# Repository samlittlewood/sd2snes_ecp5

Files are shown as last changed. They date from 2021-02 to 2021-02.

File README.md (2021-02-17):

Lattice ECP5 Transplant for SD2SNES
===================================

Based on https://github.com/mrehkopf/sd2snes

* Main changes are FPGA, RAM and power. The SNES interface and MCU are broadly the same as SD2SNES
* Prototype is populated with ECP5U-45F for easy development - 12F or 25F parts are available for same footprint. 
* MSU-1 DAC mods from https://github.com/DevLaTron/sd2snes
* USB-C (2.0) connector

Schematic: https://github.com/samlittlewood/sd2snes_ecp5/raw/main/RevB/sd2snes_ecp5.pdf

WARNING: This is still a prototype - it has managed to run games, but more than likely has some 'hilarious in hindsight' mistakes that have yet to be found.
 
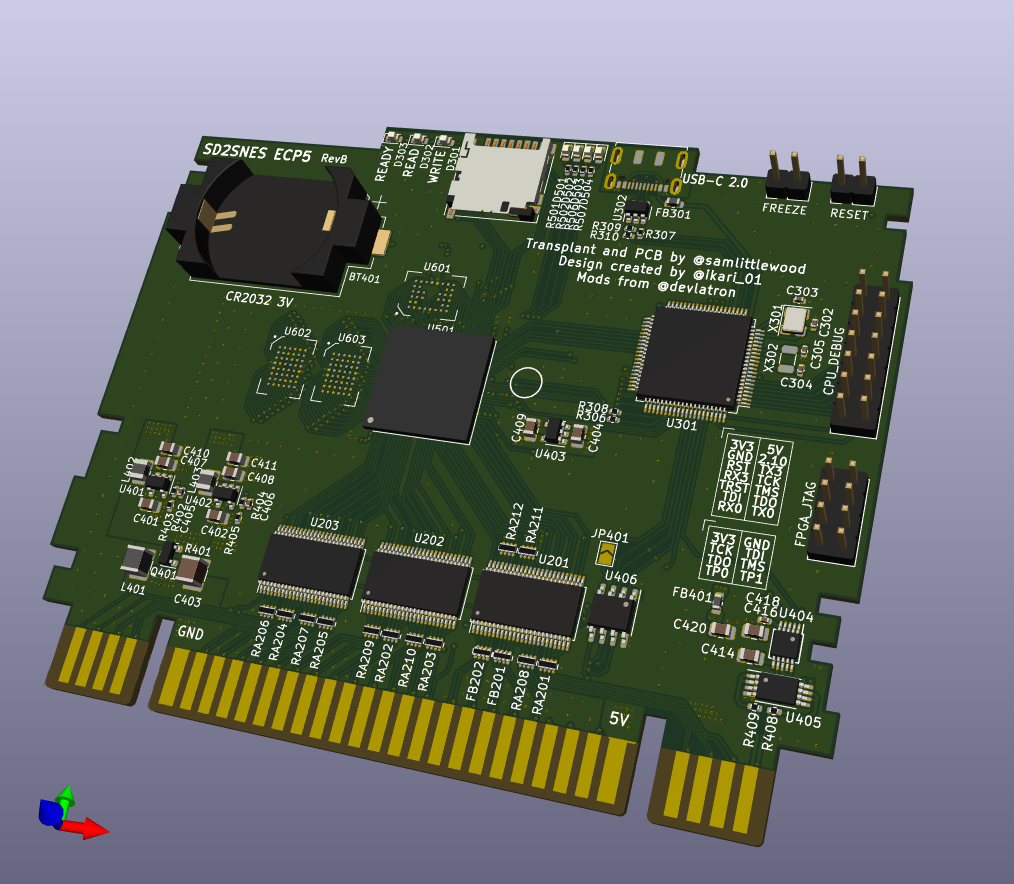
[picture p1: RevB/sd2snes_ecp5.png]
Shiny


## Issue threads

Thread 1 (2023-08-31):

Firmware Version

bigfootcontrols, 2023-08-31:
Does this fork of SD2SNES use the same firmware as mainline SD2SNES releases?  Or is there a custom firmware needed?

samlittlewood, 2023-09-04:
Hiya,

It needs custom firmware. A couple of years ago - I had a very hacked up
port of the original software & gateware, enough to get 'normal' types of
cart mostly working. I was starting to tidy it up and figure out the more
interesting carts, when the Lattice FPGA parts became unobtanium, and I
shelved it.

Looks like the parts are available again, and there has been some renewed
interest, so I'll see if I can update to latest firmware/gateware and get
it into a releasable state. The big issues are around porting the verilog
code so as to make use of the custom RAM and multipliers.

S

On Thu, 31 Aug 2023 at 18:35, bigfootcontrols ***@***.***>
wrote:

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

--
Sam Littlewood

bigfootcontrols, 2023-09-05:
That's great to hear!  It would be really cool to have a working, open-source SNES flashcart available again.  If you need beta testers I'd be interested in ordering a PCB and giving it a go, I'd be happy to put in some time testing out firmware builds.  I wish I could volunteer to help with the firmware itself but unfortunately I haven't done any coding in about 15 years lol

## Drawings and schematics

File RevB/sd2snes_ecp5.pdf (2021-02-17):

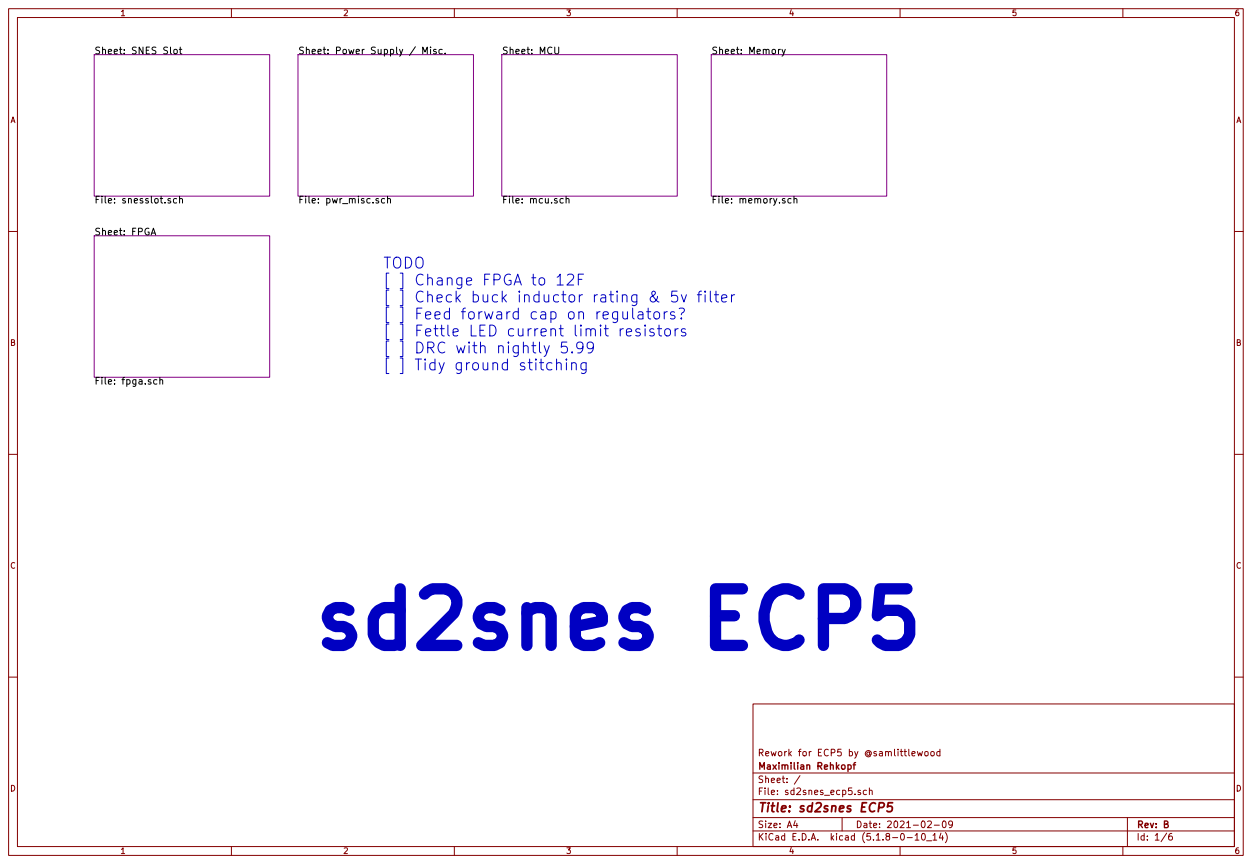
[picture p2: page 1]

File: mcu.sch Sheet: Power Supply / Misc.

TODO
[ ] Change FPGA to 12F
[ ] Check buck inductor rating & 5v filter
[ ] Feed forward cap on regulators?
[ ] Fettle LED current limit resistors
[ ] DRC with nightly 5.99
[ ] Tidy ground stitching

Rework for ECP5 by @samlittlewood
File: sd2snes_ecp5.sch Sheet: / Maximilian Rehkopf

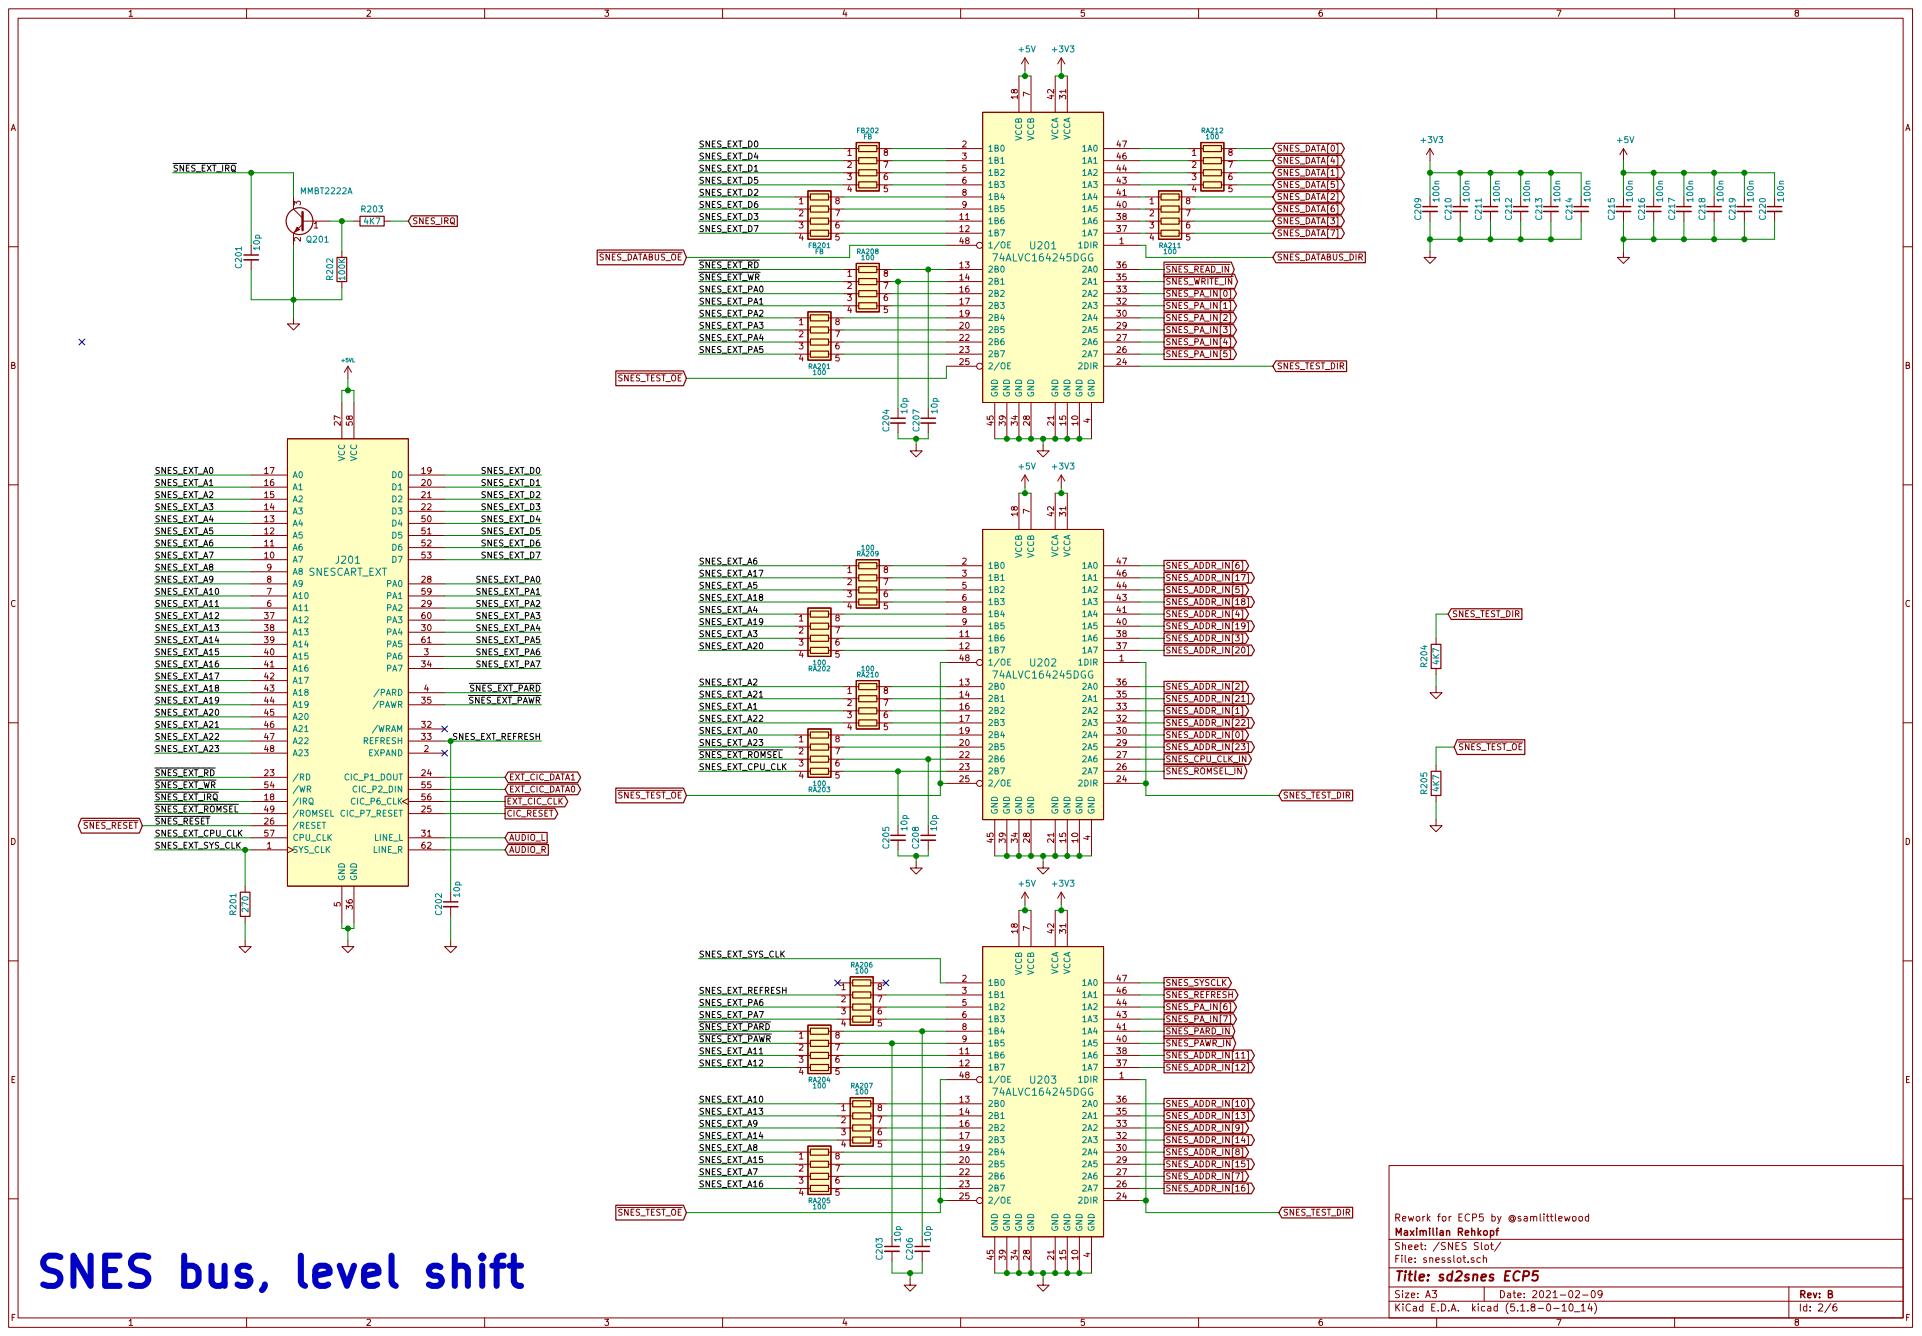
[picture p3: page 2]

SNES_EXT_A0 SNES_EXT_A1 SNES_EXT_A2 SNES_EXT_A3 SNES_EXT_A4 SNES_EXT_A5 SNES_EXT_A6 SNES_EXT_A7 SNES_EXT_A8 SNES bus, level shift

2B6 22
2B7 23

1B7 12
1/OE 48 2B0 13

File: snesslot.sch Sheet: /SNES Slot/ Maximilian Rehkopf

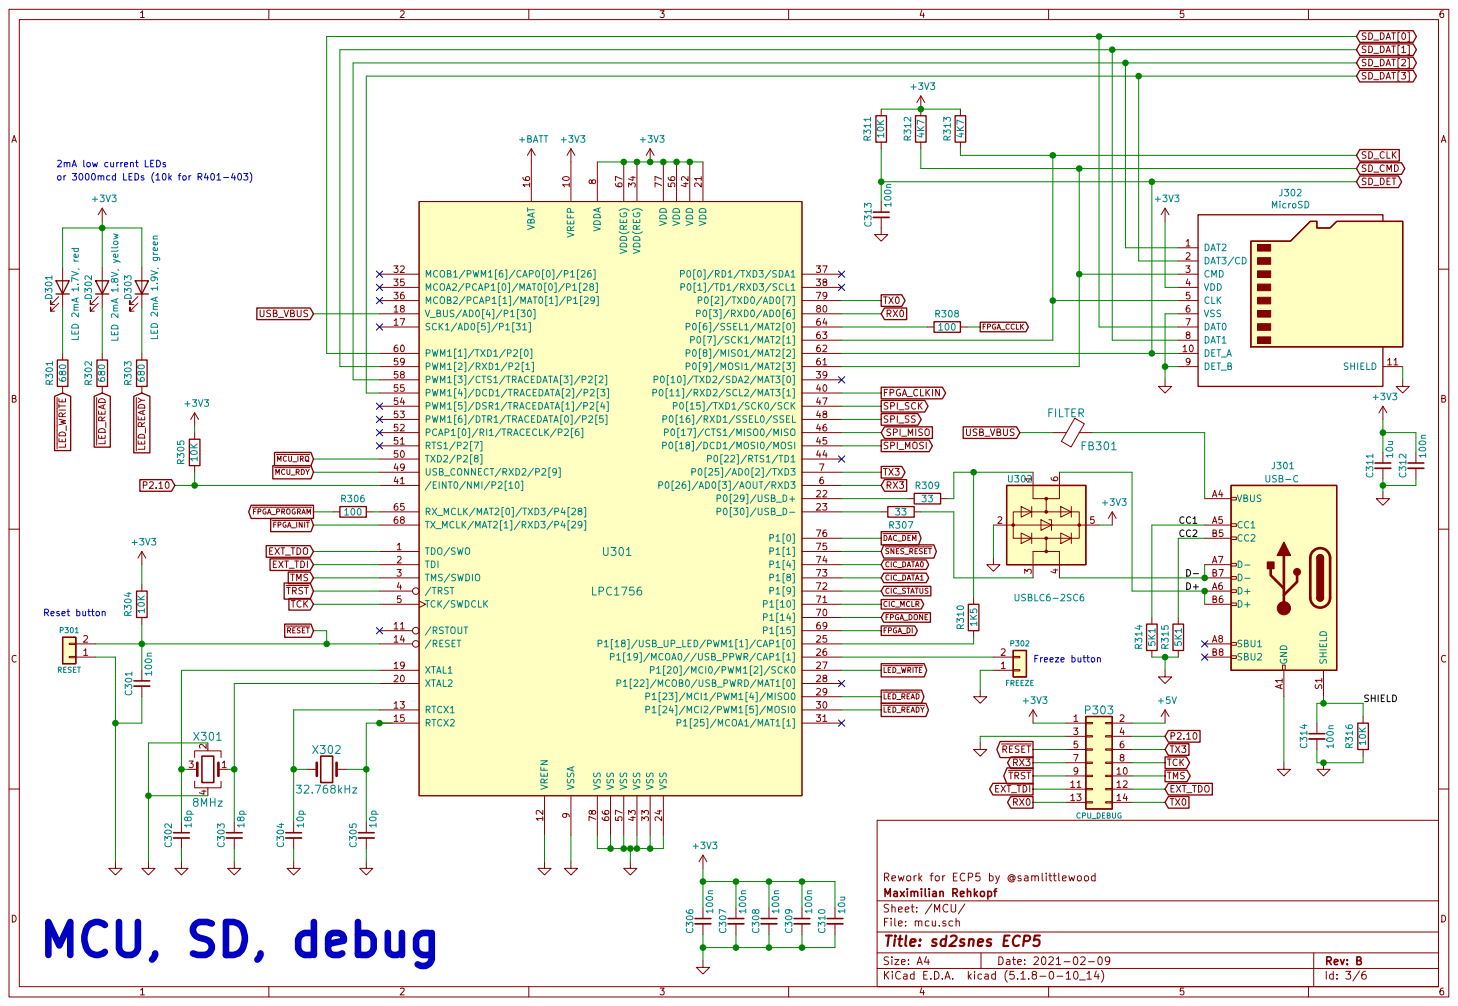
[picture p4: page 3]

or 3000mcd LEDs (10k for R401-403) 2mA low current LEDs

Freeze button Reset button

File: mcu.sch Sheet: /MCU/ Maximilian Rehkopf

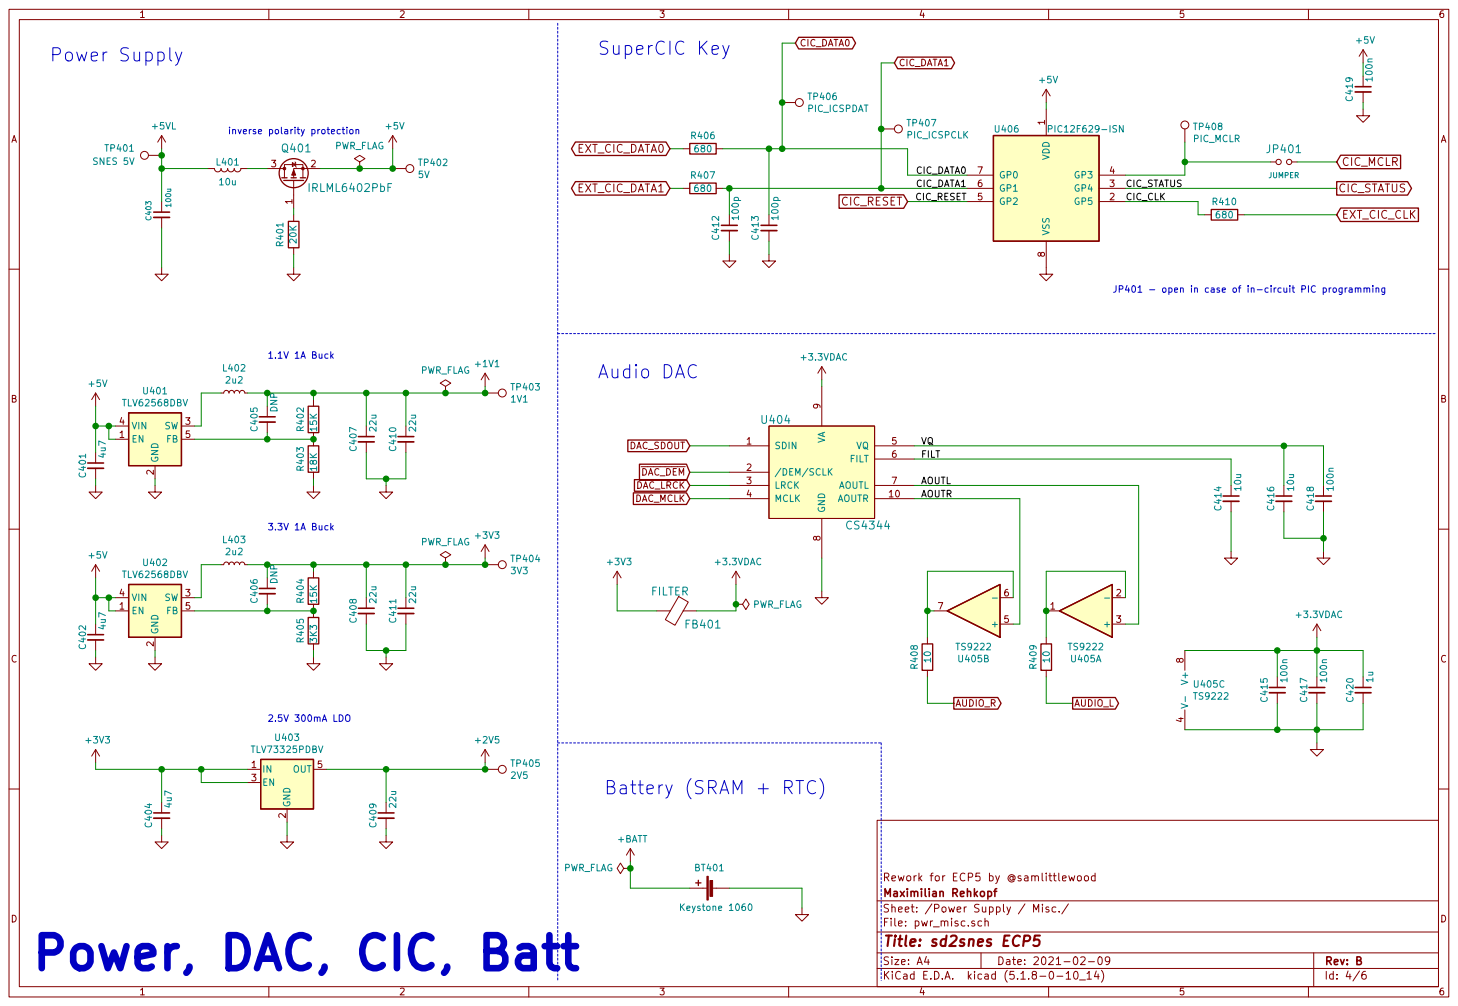
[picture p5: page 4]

SuperCIC Key Power Supply

JP401 - open in case of in-circuit PIC programming

Rework for ECP5 by @samlittlewood
Maximilian Rehkopf
Sheet: /Power Supply / Misc./
File: pwr_misc.sch
Id: 4/6 Title: sd2snes ECP5

Power, DAC, CIC, Batt

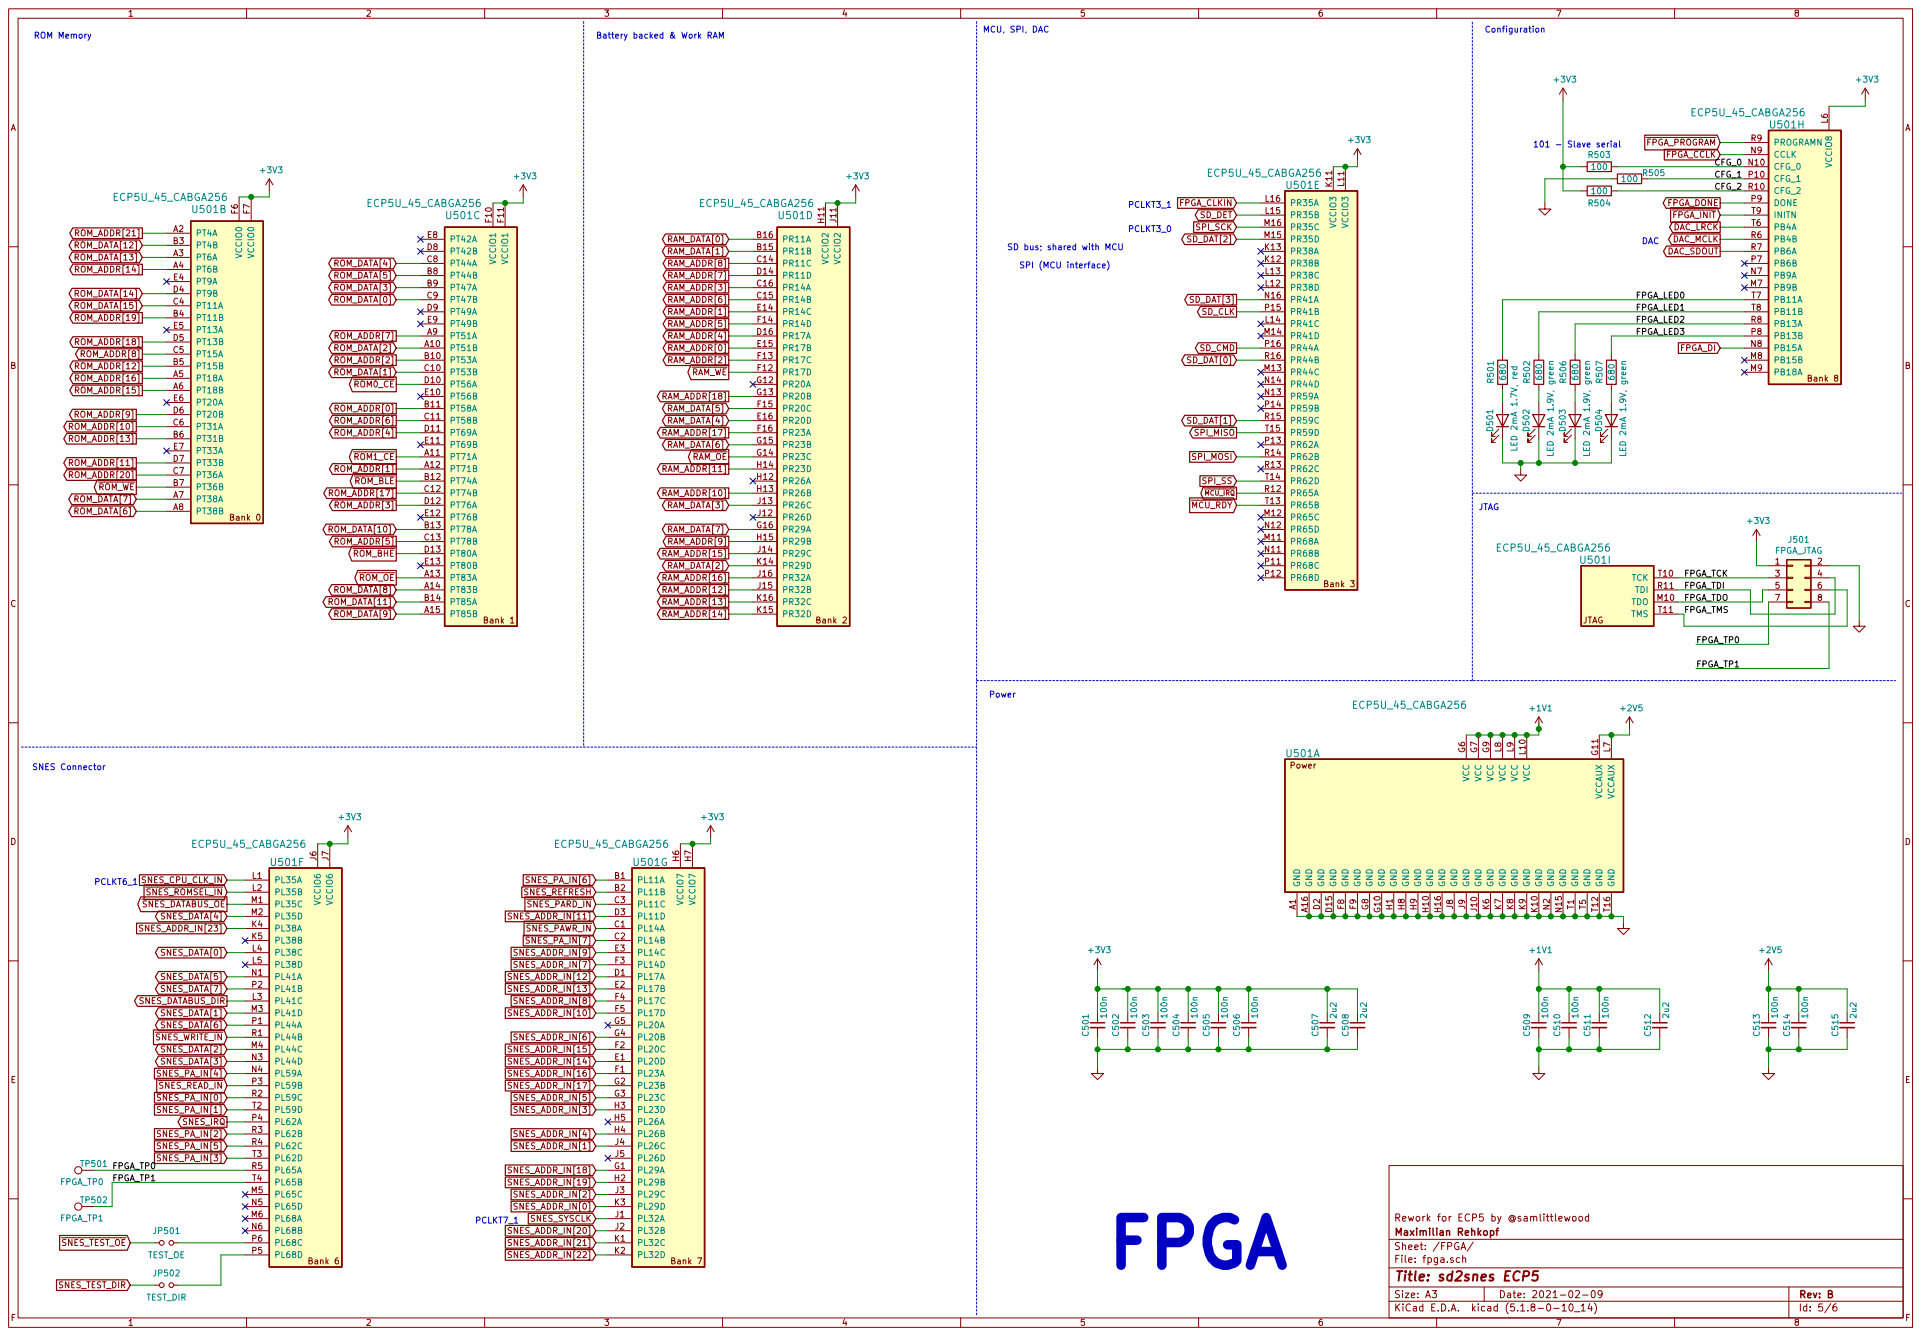
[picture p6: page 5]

SPI (MCU interface) SD bus; shared with MCU

Rework for ECP5 by @samlittlewood
File: fpga.sch Sheet: /FPGA/ Maximilian Rehkopf

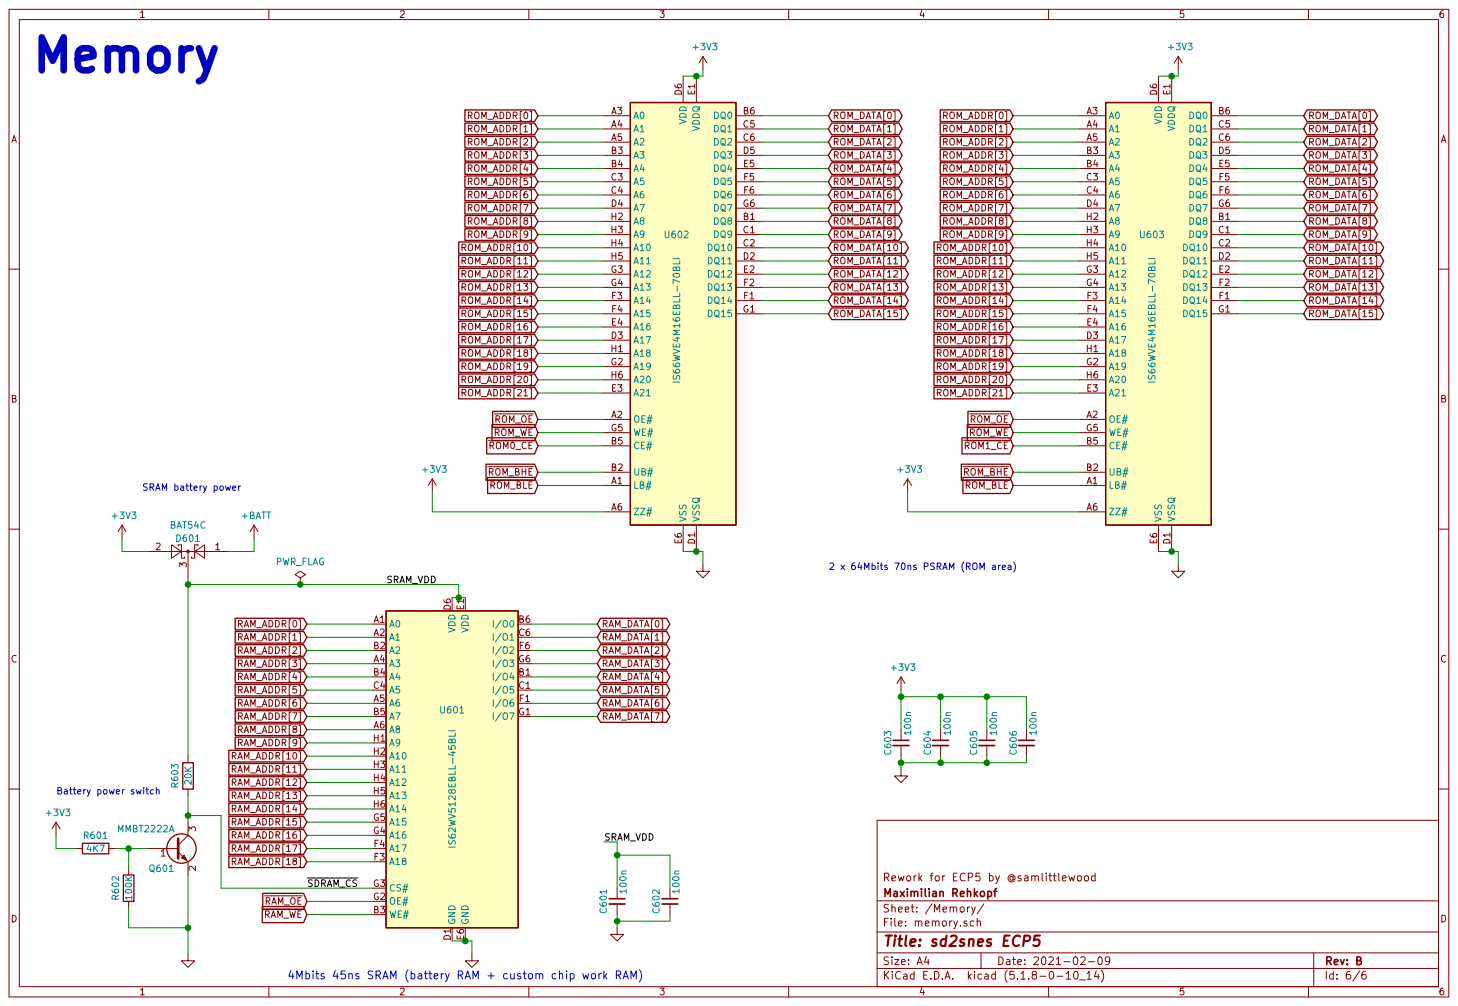
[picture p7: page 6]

Rework for ECP5 by @samlittlewood
Maximilian Rehkopf
Sheet: /Memory/
File: memory.sch
Id: 6/6 Title: sd2snes ECP5

4Mbits 45ns SRAM (battery RAM + custom chip work RAM)

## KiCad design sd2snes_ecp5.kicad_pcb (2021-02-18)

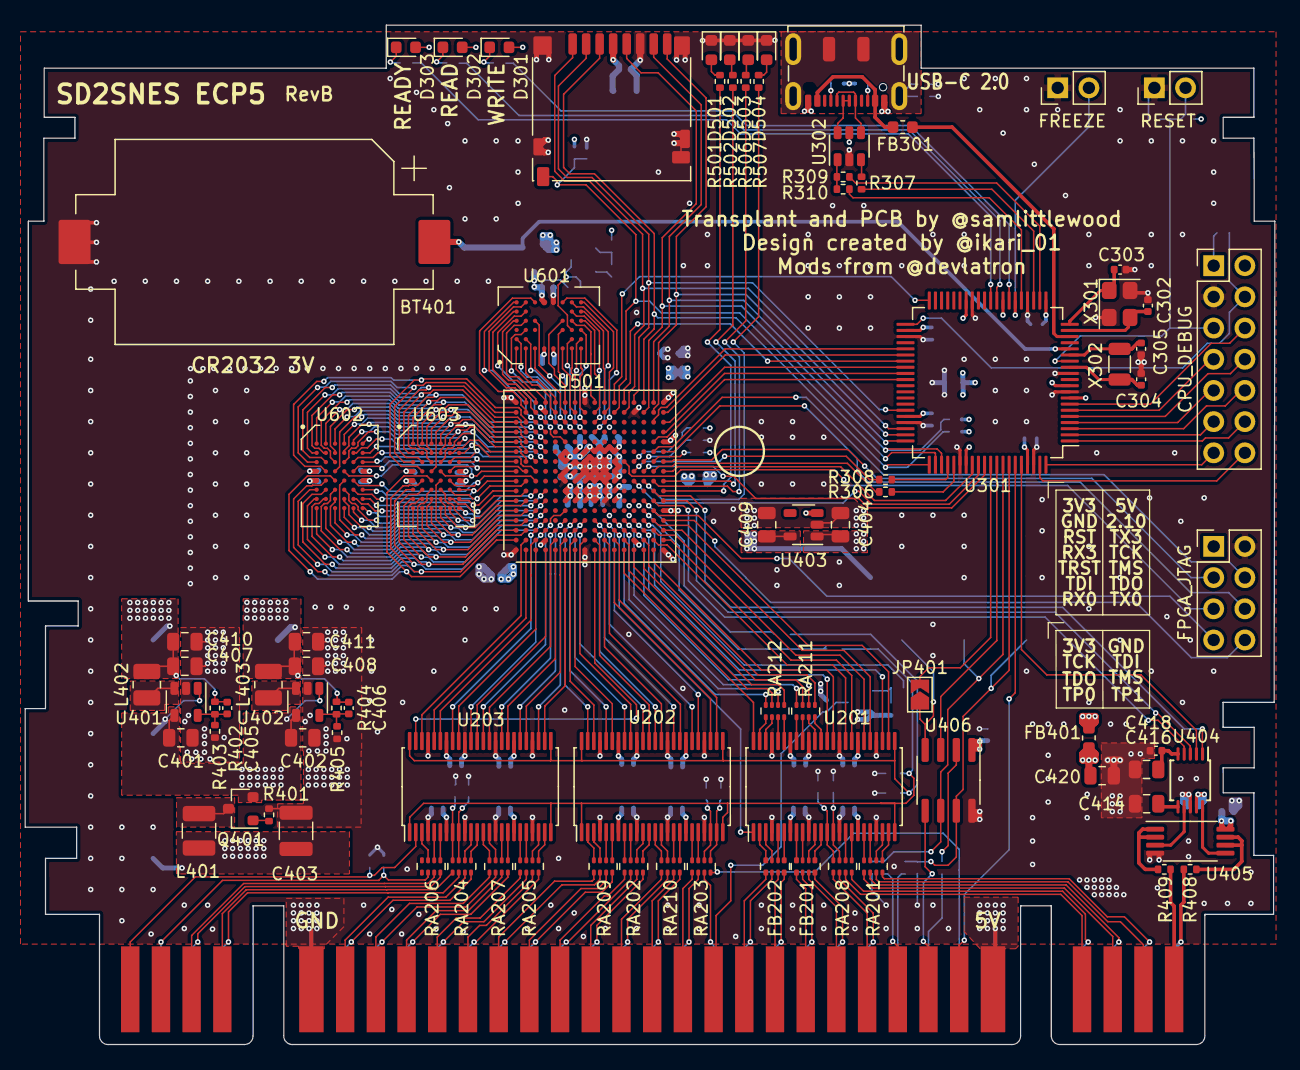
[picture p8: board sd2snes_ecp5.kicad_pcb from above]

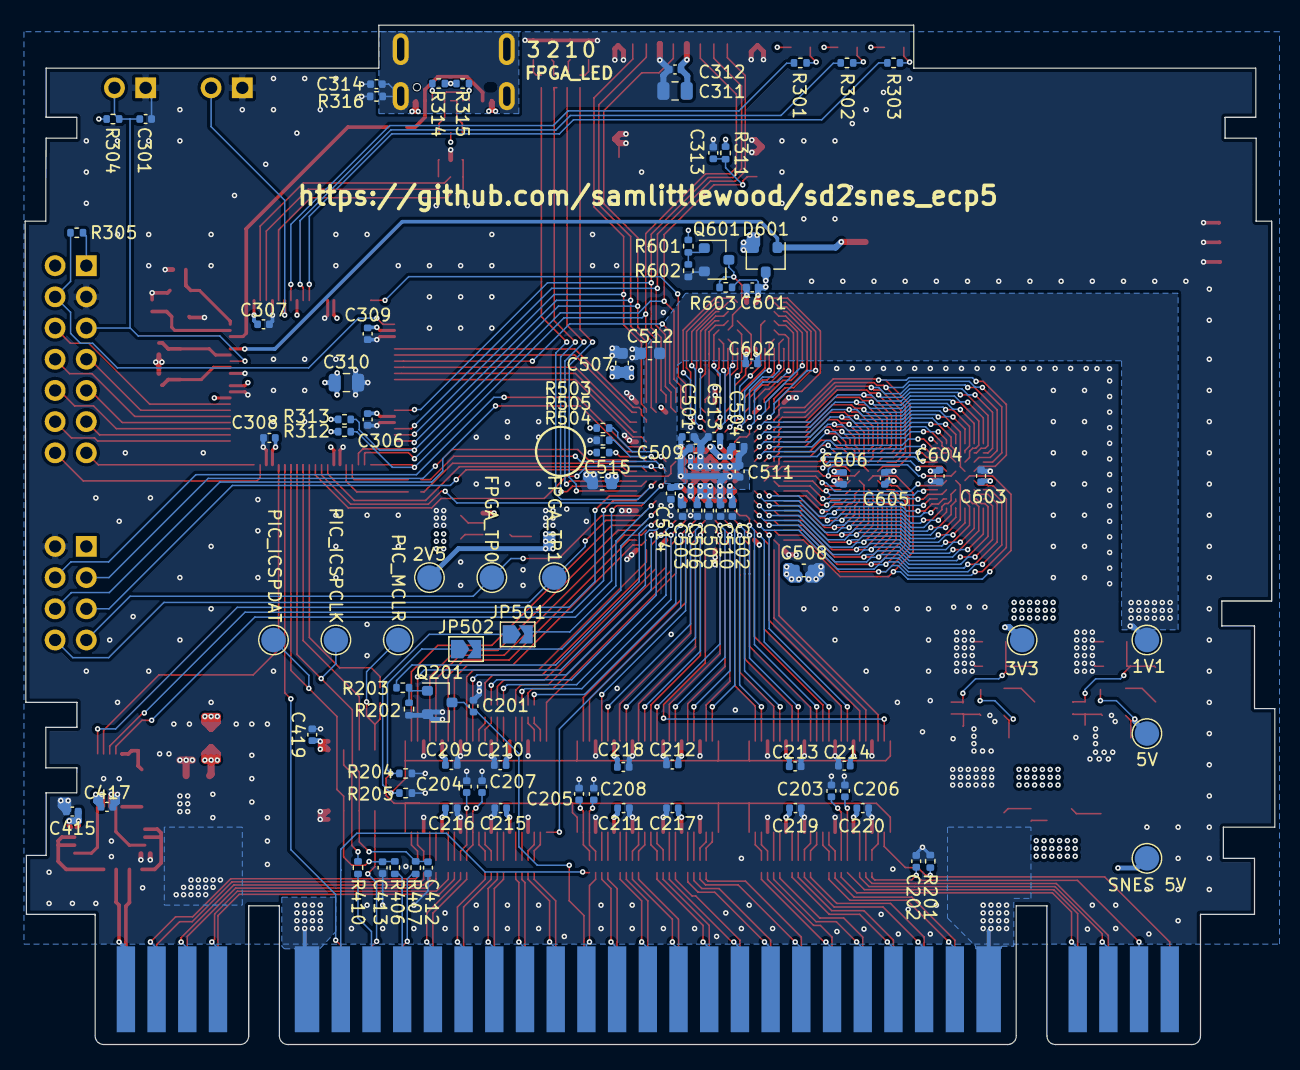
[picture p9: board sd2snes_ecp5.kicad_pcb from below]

Board: 4 copper layers, 101.8 x 83.0 mm, 184 parts (96 on the bottom side), 345 nets.

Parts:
BT401: Keystone 1060; BatteryHolder_Keystone_1060_1x2032
C201, C202, C203, C204, C205, C206, C207, C208, C304, C305: 10p; C_0402_1005Metric
C209, C210, C211, C212, C213, C214, C215, C216, C217, C218, C219, C220, C301, C306, C307, C308, C309, C312, C313, C314, C415, C417, C418, C419, C501, C502, C503, C504, C505, C506, C509, C510, C511, C513, C514, C601, C602, C603, C604, C605, C606: 100n; C_0402_1005Metric
C302, C303: 18p; C_0402_1005Metric
C310, C311, C414, C416: 10u; C_0805_2012Metric
C401, C402, C404: 4u7; C_0805_2012Metric
C403: 100u; C_1210_3225Metric
C405, C406: DNP; C_0402_1005Metric
C407, C408, C409, C410, C411: 22u; C_0805_2012Metric
C412, C413: 100p; C_0402_1005Metric
C420: 1u; C_0805_2012Metric
C507, C508, C512, C515: 2u2; C_0603_1608Metric
D301, D501: LED 2mA 1.7V, red; LED_0603_1608Metric
D302: LED 2mA 1.8V, yellow; LED_0603_1608Metric
D303, D502, D503, D504: LED 2mA 1.9V, green; LED_0603_1608Metric
D601: BAT54C; SOT-23
FB201, FB202: FB; R_Array_Convex_4x0402
FB301, FB401: FILTER; L_0603_1608Metric
J201: SNESCART_EXT
J301: USB-C; USB_C_Receptacle_JAE_DX07S016JA1
J302: MicroSD; microSD_HC_Hirose_DM3D-SF
J501: FPGA_JTAG; PinHeader_2x04_P2.54mm_Vertical
JP401: JUMPER; SolderJumper-2_P1.3mm_Open_TrianglePad1.0x1.5mm
JP501: TEST_OE; SolderJumper-2_P1.3mm_Open_TrianglePad1.0x1.5mm
JP502: TEST_DIR; SolderJumper-2_P1.3mm_Open_TrianglePad1.0x1.5mm
L401: 10u; L_1210_3225Metric
L402, L403: 2u2; L_1008_2520Metric
P301: RESET; PinHeader_1x02_P2.54mm_Vertical
P302: FREEZE; PinHeader_1x02_P2.54mm_Vertical
P303: CPU_DEBUG; PinHeader_2x07_P2.54mm_Vertical
Q201, Q601: MMBT2222A; SOT-23
Q401: IRLML6402PbF; SOT-23
R201: 270; R_0402_1005Metric
R202, R602: 100K; R_0402_1005Metric
R203, R204, R205, R312, R313, R601: 4K7; R_0402_1005Metric
R301, R302, R303, R406, R407, R410, R501, R502, R506, R507: 680; R_0402_1005Metric
R304, R305, R311, R316: 10K; R_0402_1005Metric
R306, R308, R503, R504, R505: 100; R_0402_1005Metric
R307, R309: 33; R_0402_1005Metric
R310: 1K5; R_0402_1005Metric
R314, R315: 5K1; R_0402_1005Metric
R401, R603: 20K; R_0402_1005Metric
R402, R404: 15K; R_0402_1005Metric
R403: 18K; R_0402_1005Metric
R405: 3K3; R_0402_1005Metric
R408, R409: 10; R_0402_1005Metric
RA201, RA202, RA203, RA204, RA205, RA206, RA207, RA208, RA209, RA210, RA211, RA212: 100; R_Array_Concave_4x0402
TP401: SNES 5V; TestPoint_Pad_D2.0mm
TP402: 5V; TestPoint_Pad_D2.0mm
TP403: 1V1; TestPoint_Pad_D2.0mm
TP404: 3V3; TestPoint_Pad_D2.0mm
TP405: 2V5; TestPoint_Pad_D2.0mm
TP406: PIC_ICSPDAT; TestPoint_Pad_D2.0mm
TP407: PIC_ICSPCLK; TestPoint_Pad_D2.0mm
TP408: PIC_MCLR; TestPoint_Pad_D2.0mm
TP501: FPGA_TP0; TestPoint_Pad_D2.0mm
TP502: FPGA_TP1; TestPoint_Pad_D2.0mm
U201, U202, U203: 74ALVC164245DGG; TSSOP-48_6.1x12.5mm_P0.5mm
U301: LPC1756; LQFP-80_12x12mm_P0.5mm
U302: USBLC6-2SC6; SOT-23-6
U401, U402: TLV62568DBV; SOT-23-5
U403: TLV73325PDBV; SOT-23-5
U404: CS4344; TSSOP-10_3x3mm_P0.5mm
U405: TS9222; TSSOP-8_4.4x3mm_P0.65mm
U406: PIC12F629-ISN; SOIC-8_3.9x4.9mm_P1.27mm
U501: ECP5U_45_CABGA256; Lattice_caBGA-256_14.0x14.0mm_Layout16x`6_P0.8mm_Ball0.4mm_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
U601: IS62WV5128EBLL-45BLI; TFBGA-36_6x8_6.0x8.0mm
U602, U603: IS66WVE4M16EBLL-70BLI; TFBGA-48_6x8_6.0x8.0mm
X301: 8MHz; Crystal_SMD_3225-4Pin_3.2x2.5mm
X302: 32.768kHz; Crystal_SMD_3215-2Pin_3.2x1.5mm

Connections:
+1V1: C405.1, C407.1, C410.1, C509.1, C510.1, C511.1, C512.1, L402.2, R402.1, TP403.1, U501.G6, U501.G7, U501.G9, U501.L8, U501.L9, U501.L10
+2V5: C409.1, C513.1, C514.1, C515.1, TP405.1, U403.5, U501.G11, U501.L7
+3.3VDAC: C415.1, C417.1, C420.1, FB401.1, U404.9, U405.8
+3V3: C209.1, C210.1, C211.1, C212.1, C213.1, C214.1, C306.1, C307.1, C308.1, C309.1, C310.1, C311.1, C312.1, C404.1, C406.1, C408.1, C411.1, C501.1, C502.1, C503.1, C504.1, C505.1, C506.1, C507.1, C508.1, C603.1, C604.1, C605.1, C606.1, D301.2, D302.2, D303.2, D601.2, FB401.2, J302.4, J501.1, L403.2, P303.1, R304.2, R305.2, R311.2, R312.1, R313.1, R404.1, R503.2, R504.2, R601.2, TP404.1, U201.31, U201.42, U202.31, U202.42, U203.31, U203.42, U301.8, U301.10, U301.21, U301.34, U301.42, U301.56, U301.67, U301.77, U302.5, U403.1, U403.3, U501.F6, U501.F7, U501.F10, U501.F11, U501.H6, U501.H7, U501.H11, U501.J6, U501.J7, U501.J11, U501.K11, U501.L6, U501.L11, U602.A6, U602.D6, U602.E1, U603.A6, U603.D6, U603.E1
+5V: C215.1, C216.1, C217.1, C218.1, C219.1, C220.1, C401.1, C402.1, C419.1, P303.2, Q401.2, TP402.1, U201.7, U201.18, U202.7, U202.18, U203.7, U203.18, U401.1, U401.4, U402.1, U402.4, U406.1
+5VL: C403.1, J201.27, J201.58, L401.2, TP401.1
+BATT: BT401.1, D601.1, U301.16
/FPGA/CFG_0: R503.1, U501.N10
/FPGA/CFG_1: R505.1, U501.P10
/FPGA/CFG_2: R504.1, U501.R10
/FPGA/FPGA_LED0: R501.1, U501.T7
/FPGA/FPGA_LED1: R502.1, U501.T8
/FPGA/FPGA_LED2: R506.1, U501.R8
/FPGA/FPGA_LED3: R507.1, U501.P8
/FPGA/FPGA_TCK: J501.3, U501.T10
/FPGA/FPGA_TDI: J501.4, U501.R11
/FPGA/FPGA_TDO: J501.5, U501.M10
/FPGA/FPGA_TMS: J501.6, U501.T11
/FPGA/FPGA_TP0: J501.7, TP501.1, U501.R5
/FPGA/FPGA_TP1: J501.8, TP502.1, U501.T4
/MCU/CC1: J301.A5, R314.1
/MCU/CC2: J301.B5, R315.1
/MCU/D+: J301.A6, J301.B6, U302.6
/MCU/D-: J301.A7, J301.B7, U302.4
/MCU/SHIELD: C314.1, J301.S1, R316.2
/Memory/SRAM_VDD: C601.1, C602.1, D601.3, R603.1, U601.D6, U601.E1
/Memory/~SDRAM_CS: Q601.3, R603.2, U601.G3
/Power Supply / Misc./AOUTL: U404.7, U405.3
/Power Supply / Misc./AOUTR: U404.10, U405.5
/Power Supply / Misc./CIC_CLK: R410.1, U406.2
/Power Supply / Misc./FILT: C414.1, U404.6
/Power Supply / Misc./VQ: C416.1, C418.1, U404.5
/SNES Slot/SNES_EXT_A0: J201.17, RA203.1
/SNES Slot/SNES_EXT_A1: J201.16, RA210.3
/SNES Slot/SNES_EXT_A2: J201.15, RA210.1
/SNES Slot/SNES_EXT_A3: J201.14, RA202.3
/SNES Slot/SNES_EXT_A4: J201.13, RA202.1
/SNES Slot/SNES_EXT_A5: J201.12, RA209.3
/SNES Slot/SNES_EXT_A6: J201.11, RA209.1
/SNES Slot/SNES_EXT_A7: J201.10, RA205.3
/SNES Slot/SNES_EXT_A8: J201.9, RA205.1
/SNES Slot/SNES_EXT_A9: J201.8, RA207.3
/SNES Slot/SNES_EXT_A10: J201.7, RA207.1
/SNES Slot/SNES_EXT_A11: J201.6, RA204.3
/SNES Slot/SNES_EXT_A12: J201.37, RA204.4
/SNES Slot/SNES_EXT_A13: J201.38, RA207.2
/SNES Slot/SNES_EXT_A14: J201.39, RA207.4
/SNES Slot/SNES_EXT_A15: J201.40, RA205.2
/SNES Slot/SNES_EXT_A16: J201.41, RA205.4
/SNES Slot/SNES_EXT_A17: J201.42, RA209.2
/SNES Slot/SNES_EXT_A18: J201.43, RA209.4
/SNES Slot/SNES_EXT_A19: J201.44, RA202.2
/SNES Slot/SNES_EXT_A20: J201.45, RA202.4
/SNES Slot/SNES_EXT_A21: J201.46, RA210.2
/SNES Slot/SNES_EXT_A22: J201.47, RA210.4
/SNES Slot/SNES_EXT_A23: J201.48, RA203.2
/SNES Slot/SNES_EXT_CPU_CLK: J201.57, RA203.4
/SNES Slot/SNES_EXT_D0: FB202.1, J201.19
/SNES Slot/SNES_EXT_D1: FB202.3, J201.20
/SNES Slot/SNES_EXT_D2: FB201.1, J201.21
/SNES Slot/SNES_EXT_D3: FB201.3, J201.22
/SNES Slot/SNES_EXT_D4: FB202.2, J201.50
/SNES Slot/SNES_EXT_D5: FB202.4, J201.51
/SNES Slot/SNES_EXT_D6: FB201.2, J201.52
/SNES Slot/SNES_EXT_D7: FB201.4, J201.53
/SNES Slot/SNES_EXT_PA0: J201.28, RA208.3
/SNES Slot/SNES_EXT_PA1: J201.59, RA208.4
/SNES Slot/SNES_EXT_PA2: J201.29, RA201.1
/SNES Slot/SNES_EXT_PA3: J201.60, RA201.2
/SNES Slot/SNES_EXT_PA4: J201.30, RA201.3
/SNES Slot/SNES_EXT_PA5: J201.61, RA201.4
/SNES Slot/SNES_EXT_PA6: J201.3, RA206.3
/SNES Slot/SNES_EXT_PA7: J201.34, RA206.4
/SNES Slot/SNES_EXT_REFRESH: C202.1, J201.33, RA206.2
/SNES Slot/SNES_EXT_SYS_CLK: J201.1, R201.2, U203.2
/SNES Slot/~SNES_EXT_IRQ: C201.1, J201.18, Q201.3
/SNES Slot/~SNES_EXT_PARD: J201.4, RA204.1
/SNES Slot/~SNES_EXT_PAWR: J201.35, RA204.2
/SNES Slot/~SNES_EXT_RD: J201.23, RA208.1
/SNES Slot/~SNES_EXT_ROMSEL: J201.49, RA203.3
/SNES Slot/~SNES_EXT_WR: J201.54, RA208.2
AUDIO_L: J201.31, R409.2
AUDIO_R: J201.62, R408.2
CIC_DATA0: C413.1, R406.1, TP406.1, U301.74, U406.7
CIC_DATA1: C412.1, R407.2, TP407.1, U301.73, U406.6
CIC_MCLR: JP401.2, U301.71
CIC_RESET: J201.25, U406.5
CIC_STATUS: U301.72, U406.3
DAC_LRCK: U404.3, U501.T6
DAC_MCLK: U404.4, U501.R6
DAC_SDOUT: U404.1, U501.R7
EXT_CIC_CLK: J201.56, R410.2
EXT_CIC_DATA0: J201.55, R406.2
EXT_CIC_DATA1: J201.24, R407.1
EXT_TDI: P303.11, U301.2
EXT_TDO: P303.12, U301.1
FPGA_CCLK: R308.2, U501.N9
FPGA_CLKIN: U301.40, U501.L16
FPGA_DI: U301.69, U501.N8
FPGA_DONE: U301.70, U501.P9
GND: BT401.2, C201.2, C202.2, C203.2, C204.2, C205.2, C206.2, C207.2, C208.2, C209.2, C210.2, C211.2, C212.2, C213.2, C214.2, C215.2, C216.2, C217.2, C218.2, C219.2, C220.2, C301.2, C302.2, C303.2, C304.2, C305.2, C306.2, C307.2, C308.2, C309.2, C310.2, C311.2, C312.2, C313.2, C314.2, C401.2, C402.2, C403.2, C404.2, C407.2, C408.2, C409.2, C410.2, C411.2, C412.2, C413.2, C414.2, C415.2, C416.2, C417.2, C418.2, C419.2, C420.2, C501.2, C502.2, C503.2, C504.2, C505.2, C506.2, C507.2, C508.2, C509.2, C510.2, C511.2, C512.2, C513.2, C514.2, C515.2, C601.2, C602.2, C603.2, C604.2, C605.2, C606.2, D501.1, D502.1, D503.1, D504.1, J201.5, J201.36, J301.A1, J301.A12, J301.B1, J301.B12, J302.6, J302.9, J302.11, J501.2, P301.1, P302.1, P303.3, Q201.2, Q601.2, R201.1, R202.2, R204.1, R205.1, R314.2, R315.2, R316.1, R401.1, R403.2, R405.2, R505.2, R602.2, U201.4, U201.10, U201.15, U201.21, U201.28, U201.34, U201.39, U201.45, U202.4, U202.10, U202.15, U202.21, U202.28, U202.34, U202.39, U202.45, U203.4, U203.10, U203.15, U203.21, U203.28, U203.34, U203.39, U203.45, U301.9, U301.12, U301.24, U301.33, U301.43, U301.57, U301.66, U301.78, U302.2, U401.2, U402.2, U403.2, U404.8, U405.4, U406.8, U501.A1, U501.A16, U501.D2, U501.D15, U501.F8, U501.F9, U501.G8, U501.G10, U501.H1, U501.H8, U501.H9, U501.H10, U501.H16, U501.J8, U501.J9, U501.J10, U501.K6, U501.K7, U501.K8, U501.K9, U501.K10, U501.N2, U501.N15, U501.T1, U501.T5, U501.T12, U501.T16, U601.D1, U601.E6, U602.D1, U602.E6, U603.D1, U603.E6, X301.2, X301.4
unnamed: C203.1, RA204.7, U203.9
unnamed: C204.1, RA208.7, U201.14
unnamed: C205.1, RA203.5, U202.23
unnamed: C206.1, RA204.8, U203.8
unnamed: C207.1, RA208.8, U201.13
unnamed: C208.1, RA203.6, U202.22
unnamed: C302.1, U301.19, X301.3
unnamed: C303.1, U301.20, X301.1
unnamed: C304.1, U301.13, X302.1
unnamed: C305.1, U301.15, X302.2
unnamed: C405.2, R402.2, R403.1, U401.5
unnamed: C406.2, R404.2, R405.1, U402.5
unnamed: D301.1, R301.1
unnamed: D302.1, R302.2
unnamed: D303.1, R303.2
unnamed: D501.2, R501.2
unnamed: D502.2, R502.2
unnamed: D503.2, R506.2
unnamed: D504.2, R507.2
unnamed: FB201.5, U201.12
unnamed: FB201.6, U201.11
unnamed: FB201.7, U201.9
unnamed: FB201.8, U201.8
unnamed: FB202.5, U201.6
unnamed: FB202.6, U201.5
unnamed: FB202.7, U201.3
unnamed: FB202.8, U201.2
unnamed: FB301.1, J301.A4, J301.A9, J301.B4, J301.B9
unnamed: JP401.1, TP408.1, U406.4
unnamed: JP501.2, U501.P6
unnamed: JP502.2, U501.P5
unnamed: L401.1, Q401.3
unnamed: L402.1, U401.3
unnamed: L403.1, U402.3
unnamed: P302.2, U301.26
unnamed: Q201.1, R202.1, R203.2
unnamed: Q401.1, R401.2
unnamed: Q601.1, R601.1, R602.1
unnamed: R306.2, U301.65
unnamed: R307.1, U302.3
unnamed: R307.2, U301.23
unnamed: R308.1, U301.64
unnamed: R309.1, R310.1, U302.1
unnamed: R309.2, U301.22
unnamed: R310.2, U301.25
unnamed: R408.1, U405.6, U405.7
unnamed: R409.1, U405.1, U405.2
unnamed: RA201.5, U201.23
unnamed: RA201.6, U201.22
unnamed: RA201.7, U201.20
unnamed: RA201.8, U201.19
unnamed: RA202.5, U202.12
unnamed: RA202.6, U202.11
unnamed: RA202.7, U202.9
unnamed: RA202.8, U202.8
unnamed: RA203.7, U202.20
unnamed: RA203.8, U202.19
unnamed: RA204.5, U203.12
unnamed: RA204.6, U203.11
unnamed: RA205.5, U203.23
unnamed: RA205.6, U203.22
unnamed: RA205.7, U203.20
unnamed: RA205.8, U203.19
unnamed: RA206.5, U203.6
unnamed: RA206.6, U203.5
unnamed: RA206.7, U203.3
unnamed: RA207.5, U203.17
unnamed: RA207.6, U203.16
unnamed: RA207.7, U203.14
unnamed: RA207.8, U203.13
unnamed: RA208.5, U201.17
unnamed: RA208.6, U201.16
unnamed: RA209.5, U202.6
unnamed: RA209.6, U202.5
unnamed: RA209.7, U202.3
unnamed: RA209.8, U202.2
unnamed: RA210.5, U202.17
unnamed: RA210.6, U202.16
unnamed: RA210.7, U202.14
unnamed: RA210.8, U202.13
unnamed: RA211.1, U201.41
unnamed: RA211.2, U201.40
unnamed: RA211.3, U201.38
unnamed: RA211.4, U201.37
unnamed: RA212.1, U201.47
unnamed: RA212.2, U201.46
unnamed: RA212.3, U201.44
unnamed: RA212.4, U201.43
P2.10: P303.4, R305.1, U301.41
RAM_ADDR[0]: U501.E15, U601.A1
RAM_ADDR[1]: U501.E14, U601.A2
RAM_ADDR[2]: U501.F13, U601.B2
RAM_ADDR[3]: U501.C16, U601.A4
RAM_ADDR[4]: U501.D16, U601.B4
RAM_ADDR[5]: U501.F14, U601.C4
RAM_ADDR[6]: U501.C15, U601.A5
RAM_ADDR[7]: U501.D14, U601.B5
RAM_ADDR[8]: U501.C14, U601.A6
RAM_ADDR[9]: U501.H15, U601.H1
RAM_ADDR[10]: U501.H13, U601.H2
RAM_ADDR[11]: U501.H14, U601.H3
RAM_ADDR[12]: U501.J15, U601.H4
RAM_ADDR[13]: U501.K16, U601.H5
RAM_ADDR[14]: U501.K15, U601.H6
RAM_ADDR[15]: U501.J14, U601.G5
RAM_ADDR[16]: U501.J16, U601.G4
RAM_ADDR[17]: U501.F16, U601.F4
RAM_ADDR[18]: U501.G13, U601.F3
RAM_DATA[0]: U501.B16, U601.B6
RAM_DATA[1]: U501.B15, U601.C6
RAM_DATA[2]: U501.K14, U601.F6
RAM_DATA[3]: U501.J13, U601.G6
RAM_DATA[4]: U501.E16, U601.B1
RAM_DATA[5]: U501.F15, U601.C1
RAM_DATA[6]: U501.G15, U601.F1
RAM_DATA[7]: U501.G16, U601.G1
ROM_ADDR[0]: U501.B11, U602.A3, U603.A3
ROM_ADDR[1]: U501.A12, U602.A4, U603.A4
ROM_ADDR[2]: U501.B10, U602.A5, U603.A5
ROM_ADDR[3]: U501.D12, U602.B3, U603.B3
ROM_ADDR[4]: U501.D11, U602.B4, U603.B4
ROM_ADDR[5]: U501.C13, U602.C3, U603.C3
ROM_ADDR[6]: U501.C11, U602.C4, U603.C4
ROM_ADDR[7]: U501.A9, U602.D4, U603.D4
ROM_ADDR[8]: U501.C5, U602.H2, U603.H2
ROM_ADDR[9]: U501.D6, U602.H3, U603.H3
ROM_ADDR[10]: U501.C6, U602.H4, U603.H4
ROM_ADDR[11]: U501.D7, U602.H5, U603.H5
ROM_ADDR[12]: U501.B5, U602.G3, U603.G3
ROM_ADDR[13]: U501.B6, U602.G4, U603.G4
ROM_ADDR[14]: U501.A4, U602.F3, U603.F3
ROM_ADDR[15]: U501.A6, U602.F4, U603.F4
ROM_ADDR[16]: U501.A5, U602.E4, U603.E4
ROM_ADDR[17]: U501.C12, U602.D3, U603.D3
ROM_ADDR[18]: U501.D5, U602.H1, U603.H1
ROM_ADDR[19]: U501.B4, U602.G2, U603.G2
ROM_ADDR[20]: U501.C7, U602.H6, U603.H6
ROM_ADDR[21]: U501.A2, U602.E3, U603.E3
ROM_DATA[0]: U501.C9, U602.B6, U603.B6
ROM_DATA[1]: U501.C10, U602.C5, U603.C5
ROM_DATA[2]: U501.A10, U602.C6, U603.C6
ROM_DATA[3]: U501.B9, U602.D5, U603.D5
ROM_DATA[4]: U501.C8, U602.E5, U603.E5
ROM_DATA[5]: U501.B8, U602.F5, U603.F5
ROM_DATA[6]: U501.A8, U602.F6, U603.F6
ROM_DATA[7]: U501.A7, U602.G6, U603.G6
ROM_DATA[8]: U501.A14, U602.B1, U603.B1
ROM_DATA[9]: U501.A15, U602.C1, U603.C1
ROM_DATA[10]: U501.B13, U602.C2, U603.C2
ROM_DATA[11]: U501.B14, U602.D2, U603.D2
ROM_DATA[12]: U501.B3, U602.E2, U603.E2
ROM_DATA[13]: U501.A3, U602.F2, U603.F2
ROM_DATA[14]: U501.D4, U602.F1, U603.F1
ROM_DATA[15]: U501.C4, U602.G1, U603.G1
RX0: P303.13, U301.80
RX3: P303.7, U301.6
SD_CLK: J302.5, R313.2, U301.63, U501.P15
SD_CMD: J302.3, R312.2, U301.61, U501.P16
SD_DAT[0]: J302.7, U301.60, U501.R16
SD_DAT[1]: J302.8, U301.59, U501.R15
SD_DAT[2]: J302.1, U301.58, U501.M15
SD_DAT[3]: J302.2, U301.55, U501.N16
SD_DET: C313.1, J302.10, R311.1, U301.62, U501.L15
SNES_ADDR_IN[0]: U202.30, U501.K3
SNES_ADDR_IN[1]: U202.33, U501.J4
SNES_ADDR_IN[2]: U202.36, U501.J3
SNES_ADDR_IN[3]: U202.38, U501.H3
SNES_ADDR_IN[4]: U202.41, U501.H4
SNES_ADDR_IN[5]: U202.44, U501.G3
SNES_ADDR_IN[6]: U202.47, U501.G4
SNES_ADDR_IN[7]: U203.27, U501.F3
SNES_ADDR_IN[8]: U203.30, U501.F4
SNES_ADDR_IN[9]: U203.33, U501.E3
SNES_ADDR_IN[10]: U203.36, U501.F5
SNES_ADDR_IN[11]: U203.38, U501.D3
SNES_ADDR_IN[12]: U203.37, U501.D1
SNES_ADDR_IN[13]: U203.35, U501.E2
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

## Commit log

2021-02-17 First commit - moving PCB into seperate repo. for the momwnt.
    [fpga.sch, mcu.sch, memory.sch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]
2021-02-17 RevB Gerbers and PDF.
    [sd2snes_ecp5-B_Cu.gbr, sd2snes_ecp5-B_Mask.gbr, sd2snes_ecp5-B_Paste.gbr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]
2021-02-18 Fix labels on snes slot lines.
    [fpga.sch, sd2snes_ecp5.kicad_pcb, snesslot.sch]
